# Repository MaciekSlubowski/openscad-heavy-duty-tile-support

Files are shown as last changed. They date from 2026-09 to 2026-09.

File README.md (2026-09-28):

<div align="center">
  OpenSCAD Model
  Single printed bracket
  Three printed brackets
  Empty mounted shelf
  Load test with water jugs
  <br>
  <i>From left to right: OpenSCAD model, freshly printed PETG brackets, empty wall-mounted shelf, and extreme load testing with three large water jugs (~60kg).</i>
</div>

# Floor Tile Shelf Bracket

A heavy-duty, parametric 3D-printable wall bracket designed in OpenSCAD to repurpose standard floor tiles into sturdy wall shelves. 

## Overview
This bracket features a massive solid wedge design combined with minimal mounting tabs, ensuring maximum load-bearing capacity while maintaining a clean look. The OpenSCAD file is fully parametric, allowing you to easily adjust tile width, thickness, and clearance.

## Key Features
* **Heavy-Duty Support:** The solid wedge structure supports the entire depth of the tile.
* **Front Retaining Lip:** Features a secure front lip to prevent the tile from sliding off.
* **Parametric Design:** Easily customizable variables in the `.scad` file to fit different tile dimensions.
* **Ready to Print:** The model is pre-rotated 90 degrees in the code to print flat on its side, ensuring the layer lines run perpendicular to the load for maximum mechanical strength.

## Dimensions & Compatibility
* **Target Tile:** Designed for standard tiles with a nominal width of 195 mm and 10 mm thickness.
* **Tolerances:** Includes a built-in 2.5 mm shrinkage clearance.
* **Build Volume:** The generated bracket measures approximately 227.5 x 213 mm. It is perfectly optimized to fit on 235x235 mm print beds (such as the Creality Ender-3 V2).

## Printing Recommendations
* **Material:** PETG is highly recommended due to its superior impact resistance and lower tendency to creep under continuous heavy loads compared to PLA.
* **Slicer Settings:** When setting up your profile in Ultimaker Cura or similar slicers, use at least **4-5 perimeters (walls)** and a strong structural infill (e.g., 30-40% Cubic or Gyroid).
* **Supports:** No supports are required.

## Assembly
Mount the bracket to the wall using flat-head screws (up to 6mm diameter) and wide flat washers. Ensure you use appropriate wall anchors for your wall type (e.g brick) before sliding the tile into the top recess.

## How to Print & Install

Since the model is fully parametric, you can generate an STL for your exact tile dimensions directly in OpenSCAD.

**Crucial Slicer Settings (for 60kg load):**
* **Nozzle:** 0.8 mm (for thicker, stronger extrusion lines).
* **Material:** PETG (Crucial to prevent long-term deformation/material creep under continuous heavy loads. Avoid PLA).
* **Walls/Perimeters:** 10
* **Top/Bottom Layers:** 10
* **Infill:** 30-40% Cubic
* **Supports:** None required.

**Assembly:**
Mount the bracket to the wall using flat-head screws (up to 6mm diameter) and wide flat washers. Ensure you use heavy-duty wall anchors appropriate for your wall type (wood, brick) before sliding the tile into the top recess.

## 📄 License & Credits

This project is open-source and provided strictly for personal, educational, and non-commercial purposes. You are free to explore, modify, and 3D print the bracket for your own needs.

* **Credits:** Developed and engineered by Maciej Ślubowski.
* **Disclaimer:** Always ensure your wall anchors and structural hardware are adequately rated for your intended load.

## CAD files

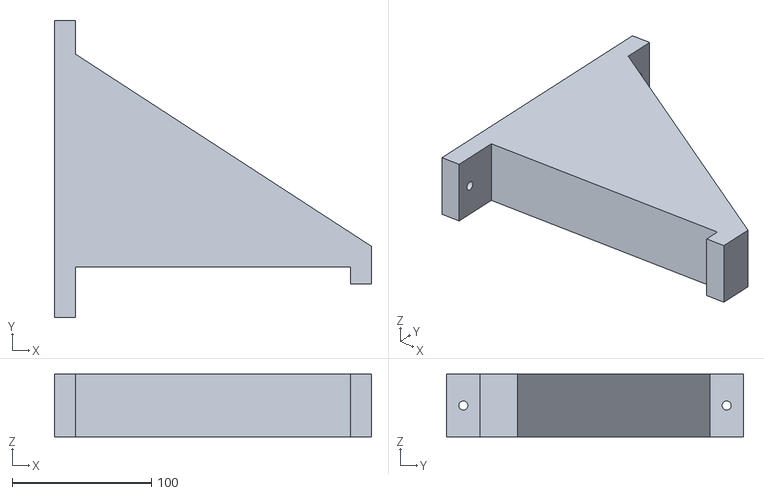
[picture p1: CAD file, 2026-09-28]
STL-heavy-duty-tile-support.stl
227.5 x 213.0 x 45.0

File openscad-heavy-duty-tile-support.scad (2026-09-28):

/*
  Floor Tile Shelf Bracket / Support
  Version: HEAVY-DUTY SOLID WEDGE + MINIMAL MOUNTING TABS
  Optimized size: 227.5 x 213 mm (Fits a 235x235 bed at 100% scale)
*/

// ==========================================
// --- TILE AND POSITIONING PARAMETERS ---
// ==========================================
tile_nominal_width = 195;    // Nominal width of the tile (19.5 cm)
shrinkage_clearance = 2.5;   // Plastic shrinkage compensation / tolerance
tile_width = tile_nominal_width + shrinkage_clearance; 
tile_thickness = 10;         // Thickness of the tile (1 cm)

// ==========================================
// --- BRACKET DESIGN PARAMETERS ---
// ==========================================
bracket_width = 45;          // Overall width/thickness of the printed bracket (4.5 cm) 
wall_base_thickness = 15;    // Thickness of the base resting against the wall

// Tile sits flush with the back section
wall_offset = wall_base_thickness; 

front_arm_thickness = 27;    // Thickness of the base at the very front (under the retaining lip)
recess_depth = 12;           // Depth of the groove holding the tile
front_lip = 15;              // Front retaining lip to secure the tile in place

// --- NEW PROPORTIONS (SOLID WEDGE) ---
wedge_height = 165;          // Height of the main supporting wedge against the wall
top_tab_height = 24;         // Minimal top mounting tab (just enough for the washer/hole)
bottom_tab_height = 24;      // Minimal bottom mounting tab (just enough for the washer/hole)

// ==========================================
// --- SCREW MOUNTING PARAMETERS ---
// ==========================================
hole_diameter = 6.5;         // Large hole for a 6mm screw with a flat washer
hole_margin = 12;            // Safe distance from the hole center to the edge of the tab

// --- AUXILIARY CALCULATIONS ---
total_length = wall_offset + tile_width + front_lip;

// Model rotated on its side (ready for 3D printing)
rotate([90, 0, 0])
shelf_bracket();

// ==========================================
// --- MAIN GENERATOR MODULE ---
// ==========================================
module shelf_bracket() {
    difference() {
        // 1. MAIN BODY (MASSIVE WEDGE + MOUNTING TABS)
        union() {
            // MAIN SUPPORT WEDGE (Covers the entire space under the tile)
            hull() {
                // Wall block (from the flat top to the very bottom of the wedge)
                translate([0, 0, -wedge_height])
                    cube([wall_base_thickness, bracket_width, wedge_height]);
                
                // Front end block (retaining lip and its direct support)
                translate([total_length - front_lip, 0, -front_arm_thickness])
                    cube([front_lip, bracket_width, front_arm_thickness]);
            }

            // TOP MOUNTING TAB (Minimal, just to fit the screw)
            translate([0, 0, 0])
                cube([wall_base_thickness, bracket_width, top_tab_height]);

            // BOTTOM MOUNTING TAB (Minimal, just to fit the screw)
            translate([0, 0, -wedge_height - bottom_tab_height])
                cube([wall_base_thickness, bracket_width, bottom_tab_height]);
        }

        // 2. CUTOUTS
        
        // Tile recess (Creates a perfect groove routed into the top of the wedge)
        translate([wall_offset, -1, -recess_depth])
            cube([tile_width, bracket_width + 2, recess_depth + 1]);

        // ==========================================
        // --- MOUNTING HOLES (FLAT) ---
        // ==========================================
        
        // TOP HOLE - perfectly centered on the minimal tab
        screw_hole(0, bracket_width/2, top_tab_height - hole_margin); 

        // BOTTOM HOLE - perfectly centered on the minimal tab
        screw_hole(0, bracket_width/2, -wedge_height - bottom_tab_height + hole_margin);
    }
}

// Module carving a simple through-hole for a screw and washer
module screw_hole(x, y, z) {
    translate([x, y, z]) rotate([0, 90, 0]) {
        // Basic through-hole cylinder
        translate([0, 0, -10])
            cylinder(h=wall_base_thickness+30, d=hole_diameter, $fn=30);
    }
}

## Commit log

2026-09-28 Update section title by removing emoji
    Removed rocket emoji from the 'How to Print & Install' section title.
2026-09-28 Update assembly instructions in README
    Removed 'concrete' from wall type options in assembly instructions.
2026-09-28 Revise assembly instructions for bracket mounting
    Updated wall type in assembly instructions from 'concrete/brick' to 'wood, brick'.
2026-09-28 Clarify wall type in assembly instructions
    Removed 'or' from the wall type description for clarity.
